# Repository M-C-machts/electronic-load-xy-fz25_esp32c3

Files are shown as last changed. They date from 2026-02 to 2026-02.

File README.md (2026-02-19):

# Electronic Load XY-FZ25 ESP32C3

A custom PCB and firmware add-on for the **XY-FZ25** electronic load, replacing the built-in measurement front-end with a more accurate solution based on the **Seeed XIAO ESP32C3** and an **INA228** high-precision power monitor.

## Overview

The XY-FZ25 is a low-cost programmable DC electronic load. This project adds a small companion board that sits alongside it and provides independent, higher-accuracy measurements of voltage, current, and power, plus a small OLED display and a self-contained LiFePO4 battery so the measurement circuit is fully isolated from the load's power rails.

### Key features

- **INA228** — 20-bit delta-sigma ADC for bus voltage, current, power, and die temperature
- **SH1106 128×64 OLED** — live display of current (mA), bus voltage (V), and die temperature (°C)
- **LiFePO4 cell** — galvanically isolated measurement supply; charged via the XIAO's USB-C port
- **Seeed XIAO ESP32C3** — compact, USB-C, Wi-Fi/BLE capable (Wi-Fi/BLE not used yet)
- Serial debug output at 115200 baud

## Repository structure

```
electronic-load-xy-fz25_esp32c3/
├── hardware/          # KiCad 7 project (schematic + PCB)
│   ├── *.kicad_pro
│   ├── *.kicad_sch
│   └── *.kicad_pcb
└── software/          # PlatformIO firmware (Arduino / ESP-IDF)
    ├── platformio.ini
    └── src/
        └── main.cpp
```

## Hardware

| Component | Description |
|---|---|
| Seeed XIAO ESP32C3 | MCU, USB-C charging, I²C host |
| INA228 | 20-bit power monitor, I²C addr `0x40` |
| SH1106 OLED 128×64 | I²C display, addr `0x3C` (or `0x3D`) |
| LiFePO4 cell | ~3.2 V nominal, ~3.6 V full |

The KiCad project is located in [`hardware/`](hardware/).

## Software

### Prerequisites

- [PlatformIO](https://platformio.org/) (VS Code extension or CLI)
- Board: **Seeed XIAO ESP32C3** (installed automatically by PlatformIO)

### Dependencies (installed automatically)

```
adafruit/Adafruit GFX Library
adafruit/Adafruit SH110X
adafruit/Adafruit INA228 Library
```

### Build & flash

```bash
# Build only
pio run

# Build and upload (USB-C)
pio run --target upload

# Open serial monitor at 115200 baud
pio device monitor
```

### Configuration

Edit the constants near the top of [`software/src/main.cpp`](software/src/main.cpp):

| Constant | Default | Purpose |
|---|---|---|
| `OLED_ADDR` | `0x3C` | OLED I²C address |
| `INA_ADDR` | `0x40` | INA228 I²C address |
| `DISPLAY_UPDATE_MS` | `500` | Display refresh interval |
| Shunt resistor | `0.015 Ω` | Passed to `ina228.setShunt()` — **must match your actual shunt** |

The INA228 is configured for 256-sample averaging and 1052 µs conversion times for low-noise readings. Adjust `setAveragingCount()` and `setVoltageConversionTime()` / `setCurrentConversionTime()` in `setup()` to trade off noise vs. update rate.

## Serial output

When connected via USB, the firmware prints one line per refresh interval:

```
I=123.456 mA  Vbus=3.3012 V  Tdie=28.50 C
```

## License

MIT

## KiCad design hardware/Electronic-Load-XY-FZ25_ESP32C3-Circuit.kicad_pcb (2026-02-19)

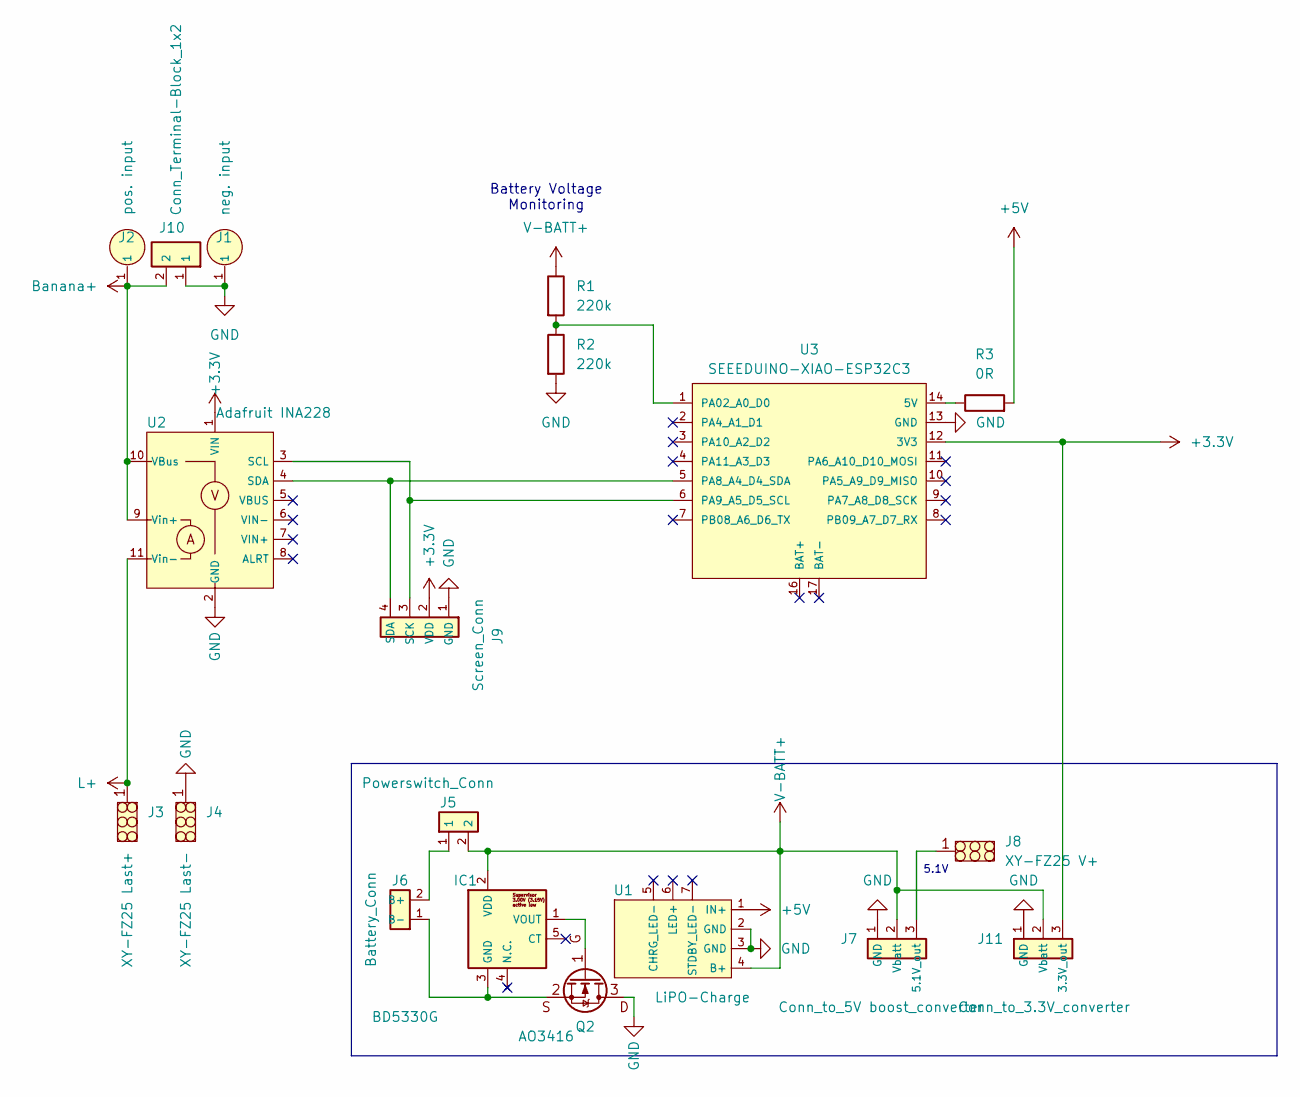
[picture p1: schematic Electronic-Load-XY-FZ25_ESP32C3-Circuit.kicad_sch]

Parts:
IC1: BD5330G; SOT95P280X125-5M; Mouser Part Number 755-BD5330G-2MTR
J1, J2: Banana-Socket; banana-socket; Mouser Part Number 534-575-4
J3, J4: mech.-solder-pad_large; Mechc.-solder-pad-large
J5, J6: Conn_1x2_PH; Mechc.-solder-pad_1x2
J7, J11: Conn_1x3_PH; Mechc.-solder-pad_1x3
J8: mech.-solder-pad; Mechc.-solder-pad
J9: Conn_1x4_PH; Conn_1x4_PH_drill dot
J10: Conn_Terminal-Block_1x2
Q2: AO3416; SOT-23
R1, R2: 220k; R_0805_2012Metric
R3: 0R; R_1206_3216Metric_Pad1.30x1.75mm_HandSolder
U1: LiPO-Charge; TP5000-Charge-IC_smal-led
U2: Adafruit INA228; INA228-Footprint
U3: SEEEDUINO-XIAO-ESP32C3

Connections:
+3.3V: J9.2 (VDD), J11.3 (3.3V_out), U2.1 (VIN), U3.12 (3V3)
+5V: R3.2, U1.1 (IN+)
Banana+: J2.1, J10.2, U2.9 (Vin+), U2.10 (VBus)
GND: J1.1, J4.1, J7.1 (GND), J9.1 (GND), J10.1, J11.1 (GND), Q2.3 (D), R2.2, U1.2 (GND), U1.3 (GND), U2.2 (GND), U3.13 (GND)
L+: J3.1, U2.11 (Vin-)
unnamed: IC1.3 (GND), J6.1 (B-), Q2.2 (S)
unnamed: IC1.1 (VOUT), Q2.1 (G)
unnamed: J5.1, J6.2 (B+)
unnamed: J7.3 (5.1V_out), J8.1
unnamed: J9.3 (SCK), U2.3 (SCL), U3.6 (PA9_A5_D5_SCL)
unnamed: J9.4 (SDA), U2.4 (SDA), U3.5 (PA8_A4_D4_SDA)
unnamed: R3.1, U3.14 (5V)
unnamed: R1.2, R2.1, U3.1 (PA02_A0_D0)
V-BATT+: IC1.2 (VDD), J5.2, J7.2 (Vbatt), J11.2 (Vbatt), R1.1, U1.4 (B+)

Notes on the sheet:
Battery Voltage Monitoring
5.1V

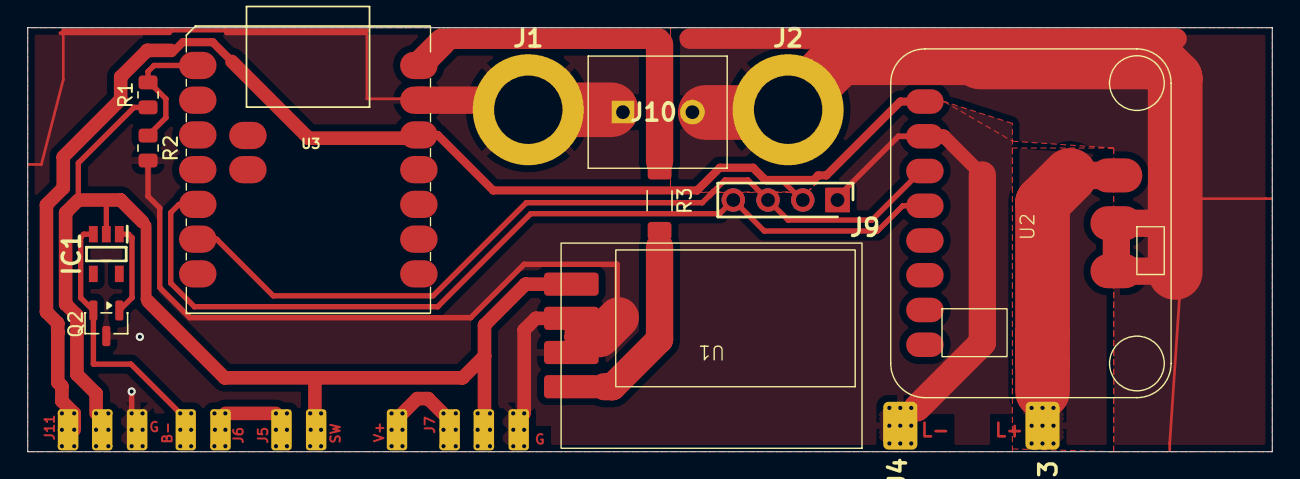
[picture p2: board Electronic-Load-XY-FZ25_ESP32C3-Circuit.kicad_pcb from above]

Board: 2 copper layers, 91.0 x 31.0 mm, 19 parts (0 on the bottom side), 14 nets.

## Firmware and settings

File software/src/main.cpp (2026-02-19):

#include <Arduino.h>
#include <Wire.h>

#include <Adafruit_GFX.h>
#include <Adafruit_SH110X.h>

#include <Adafruit_INA228.h>

// --- I2C addresses (typical) ---
static constexpr uint8_t OLED_ADDR = 0x3C;     // sometimes 0x3D
static constexpr uint8_t INA_ADDR    = 0x40;

// --- SH1106 128x64 over I2C ---
Adafruit_SH1106G oled(128, 64, &Wire, -1);

// --- INA228 ---
Adafruit_INA228 ina228;

// Pick a display refresh that is <= INA228 "new-data" cadence
static constexpr uint32_t DISPLAY_UPDATE_MS = 500;

static bool oled_begin_try(uint8_t addr) {
    return oled.begin(addr, true); // addr, reset=true
}

void setup() {
    Serial.begin(115200);
    delay(1000);

    Wire.begin();
    // Optional: faster I2C transfers (doesn't change measurement accuracy)
    // Wire.setClock(400000);

    // OLED init (try 0x3C then 0x3D)
    if (!(oled_begin_try(0x3C) || oled_begin_try(0x3D))) {
        Serial.println("SH1106 init failed");
        while (true) delay(1000);
    }

    oled.clearDisplay();
    oled.setTextColor(SH110X_WHITE);
    oled.setTextSize(1);
    oled.setCursor(0, 0);
    oled.println("OLED OK");
    oled.display();

    // INA228 init
    if (!ina228.begin(INA_ADDR, &Wire)) {
        Serial.println("INA228 init failed");
        oled.clearDisplay();
        oled.setCursor(0, 0);
        oled.println("INA228 init failed");
        oled.display();
        while (true) delay(1000);
    }

    // IMPORTANT: set the *real* shunt value you are using.
    // Adafruit INA228 breakout uses 0.015 ohm shunt.
    ina228.setShunt(0.015f, 10.0f);

    // "Accurate-looking": internal averaging + longer conversion times = less noise, slower updates
    ina228.setAveragingCount(INA228_COUNT_256);
    ina228.setVoltageConversionTime(INA228_TIME_1052_us);
    ina228.setCurrentConversionTime(INA228_TIME_1052_us);
    ina228.setTemperatureConversionTime(INA2XX_TIME_150_us);
}

void loop() {
    static uint32_t last = 0;
    uint32_t now = millis();
    if (now - last < DISPLAY_UPDATE_MS)
        return;
    last = now;

    // Read values
    const float i_mA    = ina228.getCurrent_mA();
    const float v_bus = ina228.getBusVoltage_V();
    const float t_die = ina228.readDieTemp();

    // OLED output
    oled.clearDisplay();
    oled.setCursor(0, 0);

    oled.setTextSize(1);
    oled.print("INA228  Tdie ");
    oled.print(t_die, 2);
    oled.print(" C\n\n");

    oled.setTextSize(2);
    oled.print("I ");
    oled.print(i_mA, 1);
    oled.print("mA\n");

    oled.setTextSize(1);
    oled.print("\n");
    oled.setTextSize(2);

    oled.print("U ");
    oled.print(v_bus, 4);
    oled.print(" V\n");

    oled.display();

    // Optional serial debug
    Serial.printf("I=%.3f mA  Vbus=%.4f V  Tdie=%.2f C\n", i_mA, v_bus, t_die);
}
